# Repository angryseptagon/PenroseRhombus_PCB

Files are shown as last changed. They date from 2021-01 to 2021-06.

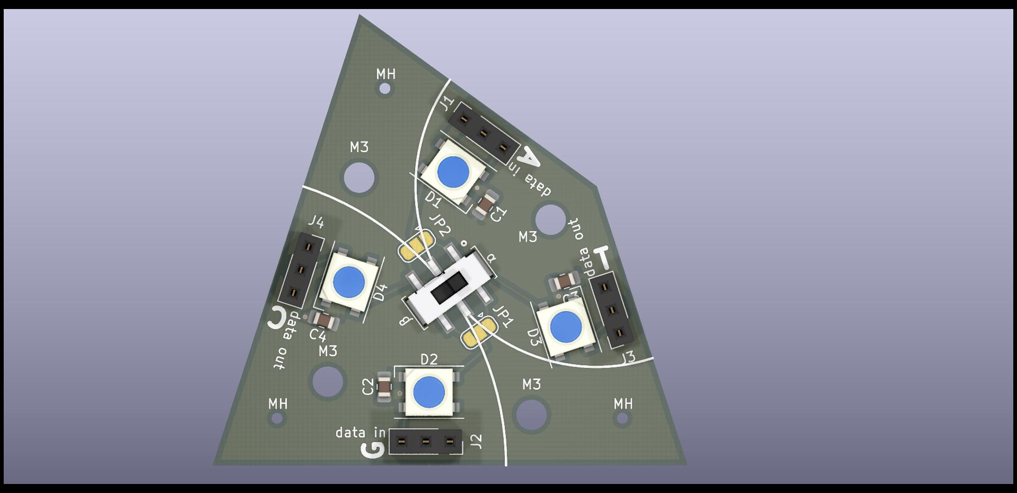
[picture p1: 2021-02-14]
Images/penrosekite_3drender.jpg

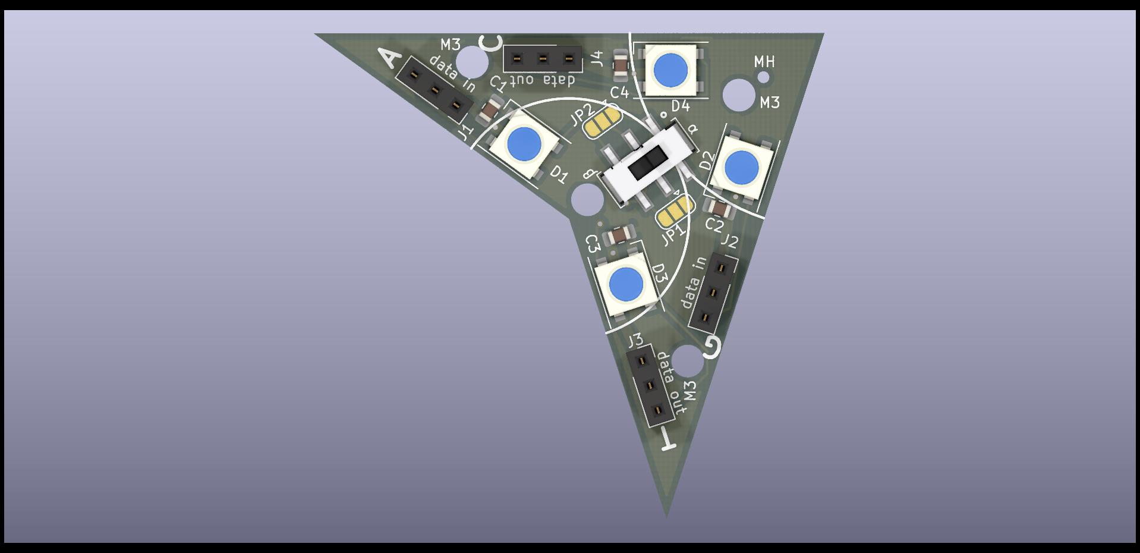
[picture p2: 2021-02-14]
Images/penrosedart_3drender.jpg

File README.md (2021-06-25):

# penroserombus_PCB
PCBs to make penrose tilings with addressable LEDs. in order to make a continous data signal, the data follows marking shown on PCB. these markings form closed loops, however loops can be merged using the switch onboard. They link together using 5mm U shaped single row connectors.
|P3 tiling|P2 tiling|
|---|---|
| thin Rhombus | Kite |
|thick Rhombus|Dart|

how switch position routes data:

Diagram

Materials per board:

4x SK6812 (or compatable ws2812b) 5050 leds - https://www.aliexpress.com/item/32814778563.html?spm=a2g0o.cart.0.0.119f3c00zzKG71&mp=1

4x 1x3 female 2.54 mm spaced headers - https://a.aliexpress.com/_mLI1pO5

4x 100 nf decoupling capacitors in 0805 size - 

?x 5mm U shaped connectors 2.54mm spacing. - https://www.aliexpress.com/item/4001034220522.html?spm=a2g0o.cart.0.0.74ea3c00vI7Rsv&mp=1

1x dpdt MSS22D18 switch - https://www.aliexpress.com/item/4000684780091.html?spm=a2g0o.cart.0.0.4ff63c00xiN8D5&mp=1

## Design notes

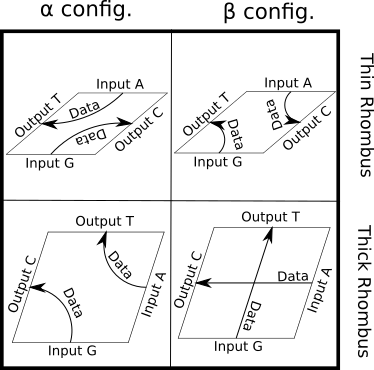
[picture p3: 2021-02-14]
Images/dataDiagram.png

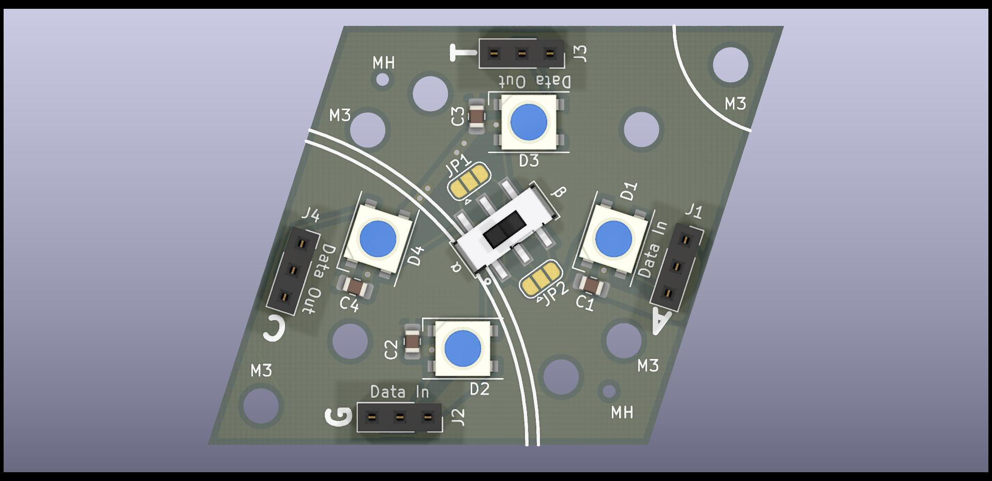
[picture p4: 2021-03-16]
Images/thick_rombus_3drender.jpg

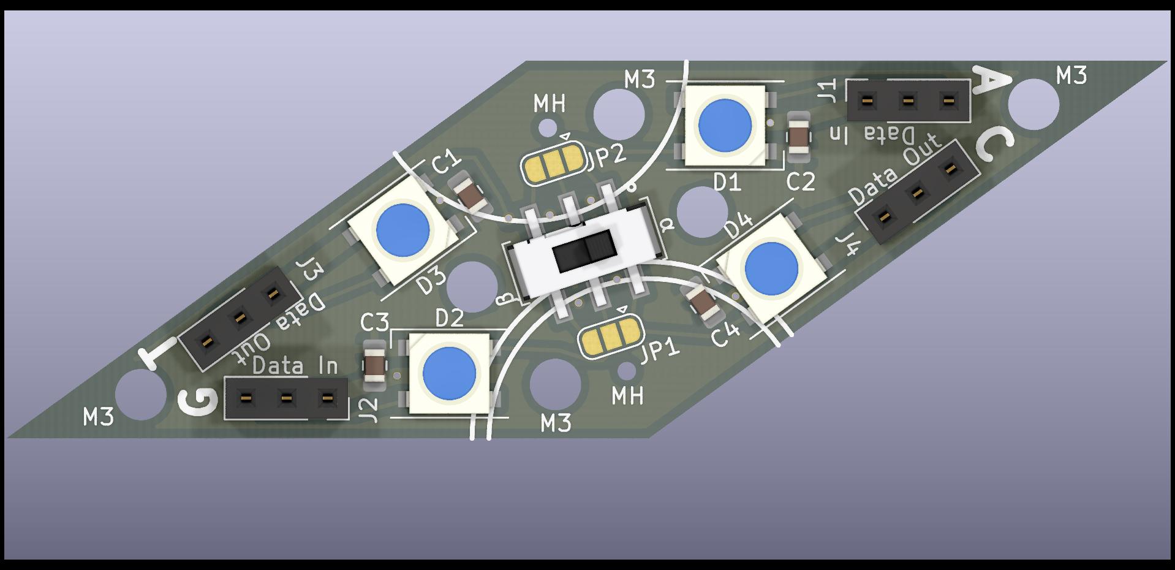
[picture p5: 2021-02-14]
Images/thin_rombus_3drender.jpg

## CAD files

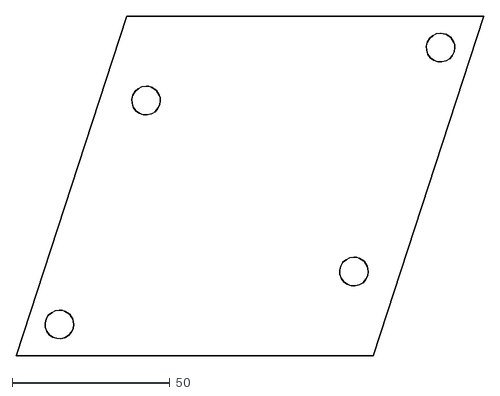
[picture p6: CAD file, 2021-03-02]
Images/penroserombus_thick_diffusercut.dxf
148.4 x 107.8

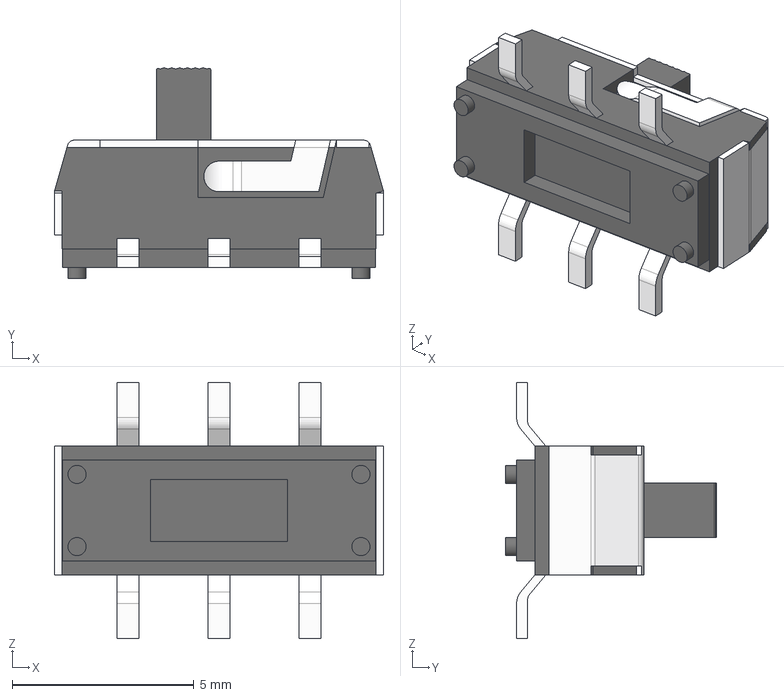
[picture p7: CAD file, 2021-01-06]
MSS22D18 Switch v3.step
9.05 x 5.79 x 7.05 mm

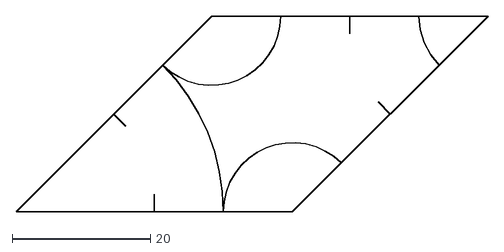
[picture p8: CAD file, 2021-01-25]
planning sketches/amann45.dxf
68.3 x 28.3

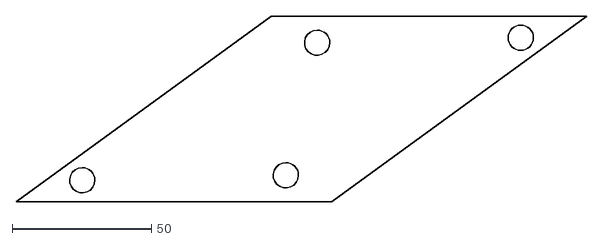
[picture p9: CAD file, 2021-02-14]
Images/penroserombus_thin_Diffusercut.dxf
205.1 x 66.6

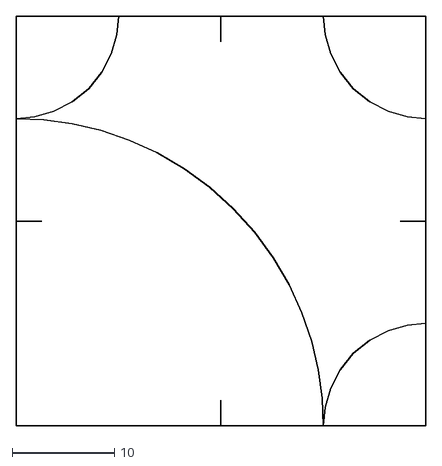
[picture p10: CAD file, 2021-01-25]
planning sketches/amannsquare.dxf
40.0 x 40.0

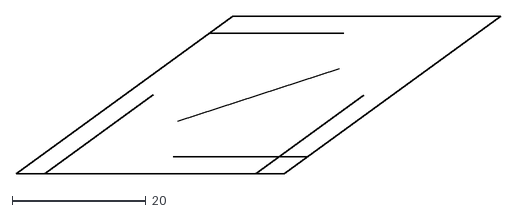
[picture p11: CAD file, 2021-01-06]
test5.dxf
72.4 x 23.5

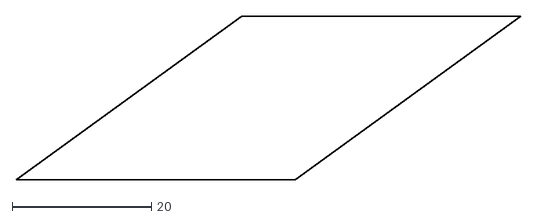
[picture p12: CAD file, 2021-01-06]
test3.dxf
72.4 x 23.5

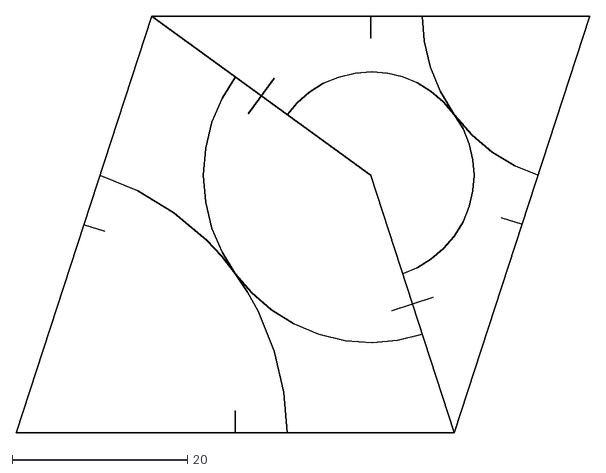
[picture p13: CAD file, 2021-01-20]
planning sketches/kiteanddarttest.dxf
65.4 x 47.6

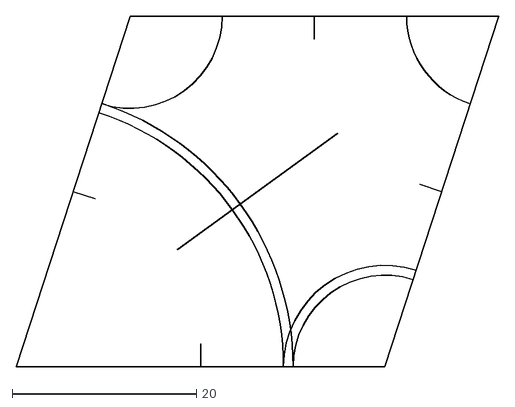
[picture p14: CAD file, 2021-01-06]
planning sketches/fixed72v2.dxf
52.4 x 38.0

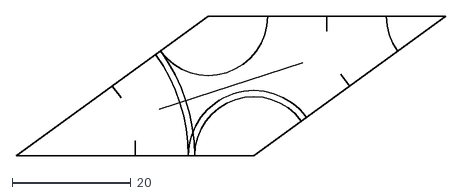
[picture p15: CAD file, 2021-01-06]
planning sketches/fixed36v2.dxf
72.4 x 23.5

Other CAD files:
planning sketches/untitled.dxf

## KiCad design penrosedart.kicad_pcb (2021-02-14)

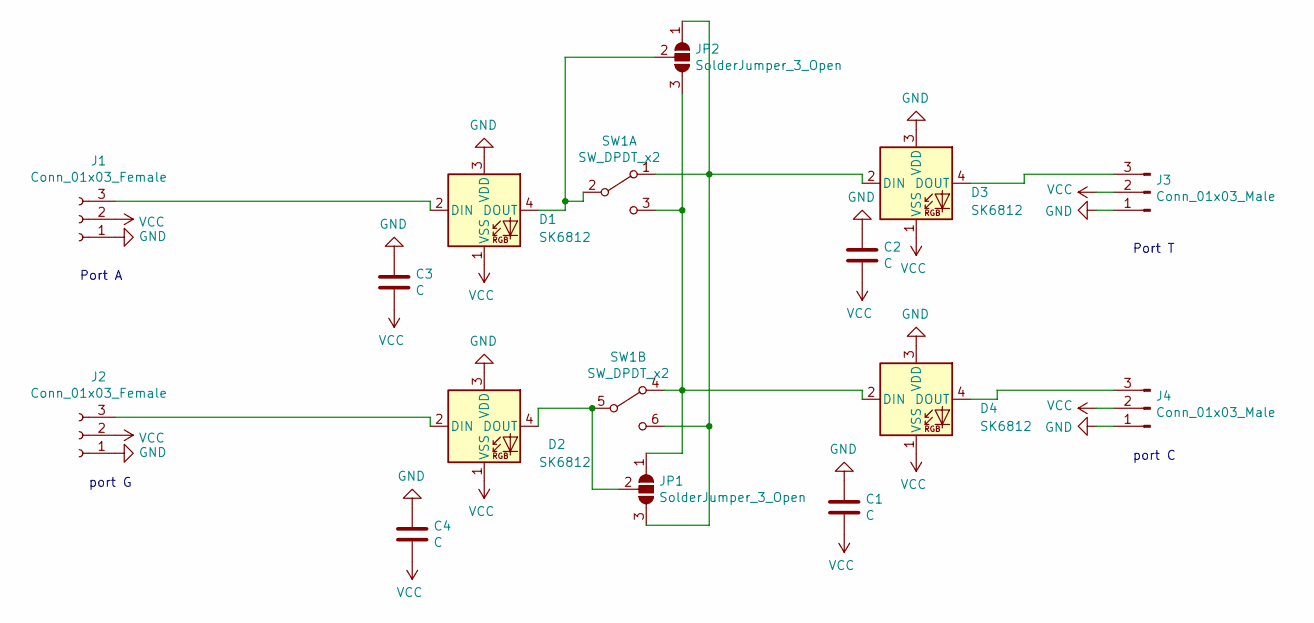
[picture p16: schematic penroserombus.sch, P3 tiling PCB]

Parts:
C1, C2, C3, C4: C; C_0805_2012Metric_Pad1.18x1.45mm_HandSolder
D1, D2, D3, D4: SK6812; LED_SK6812_PLCC4_5.0x5.0mm_P3.2mm
J1, J2: Conn_01x03_Female; PinSocket_1x03_P2.54mm_Vertical
J3, J4: Conn_01x03_Male; PinSocket_1x03_P2.54mm_Vertical
JP1, JP2: SolderJumper_3_Open; SolderJumper-3_P1.3mm_Open_RoundedPad1.0x1.5mm
SW1: SW_DPDT_x2; Aliexpress_slideswitch_2P2T

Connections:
GND: C1.1, C2.1, C3.1, C4.1, D1.3 (VDD), D2.3 (VDD), D3.3 (VDD), D4.3 (VDD), J1.1, J2.1, J3.1, J4.1
unnamed: D1.2 (DIN), J1.3
unnamed: D1.4 (DOUT), JP2.2 (C), SW1.2 (B)
unnamed: D2.2 (DIN), J2.3
unnamed: D2.4 (DOUT), JP1.2 (C), SW1.5 (B)
unnamed: D3.2 (DIN), JP1.3 (B), JP2.1 (A), SW1.1 (A), SW1.6 (C)
unnamed: D3.4 (DOUT), J3.3
unnamed: D4.2 (DIN), JP1.1 (A), JP2.3 (B), SW1.3 (C), SW1.4 (A)
unnamed: D4.4 (DOUT), J4.3
VCC: C1.2, C2.2, C3.2, C4.2, D1.1 (VSS), D2.1 (VSS), D3.1 (VSS), D4.1 (VSS), J1.2, J2.2, J3.2, J4.2

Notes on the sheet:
port G
port C
Port A
Port T

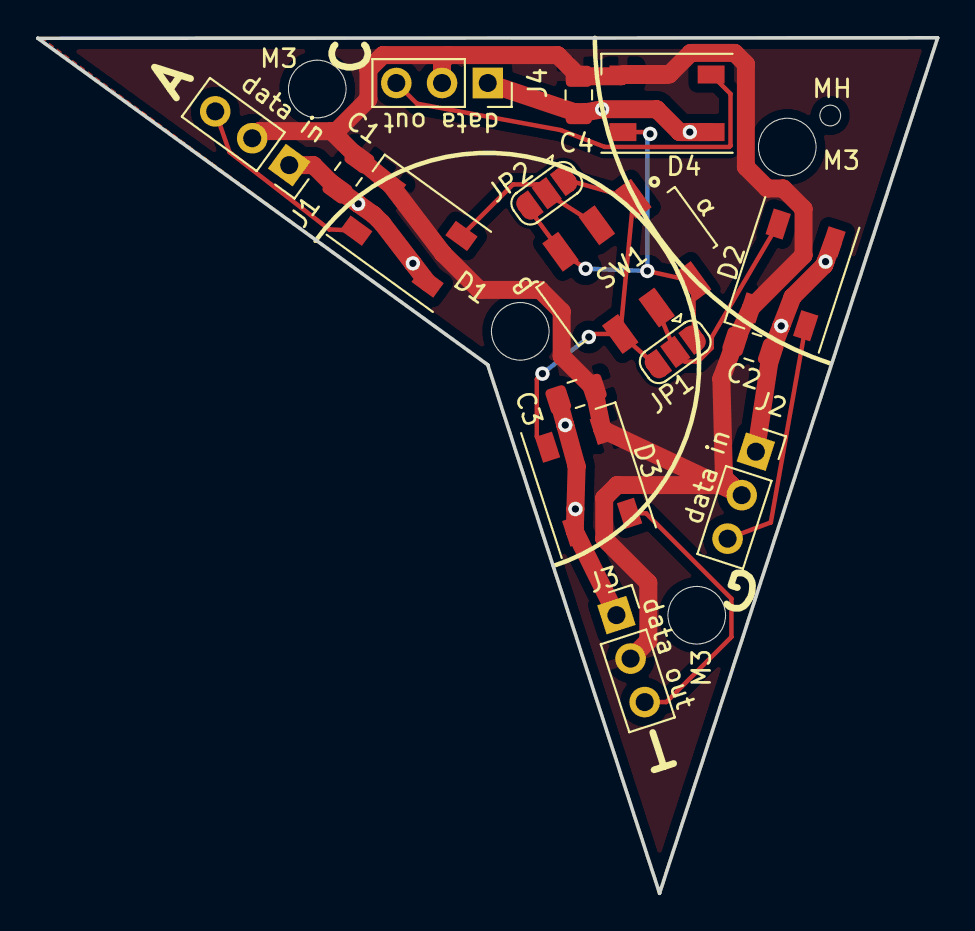
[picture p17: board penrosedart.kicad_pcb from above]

Board: 2 copper layers, 50.0 x 47.5 mm, 20 parts (0 on the bottom side), 10 nets.

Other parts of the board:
M3, M3#2, M3#3, M3#4: MountingHole_3.2mm_M3_ISO7380
MH: Pushpin_mountinghole

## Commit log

2021-01-06 initial upload
    learning how to use github, might goof it up
    [coordinate.ods, penroserombus.sch, penroserombus_thick_40mm.kicad_pcb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]
2021-01-06 initial upload
    idk whats going on anymore
    [penroserombus_thin_40mm-B_Cu.gbr, penroserombus_thin_40mm-B_Mask.gbr, penroserombus_thin_40mm-B_Paste.gbr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]
2021-01-06 deleting some trash
    [penroserombus_thin_40mm-B_Cu.gbr, penroserombus_thin_40mm-B_Mask.gbr, penroserombus_thin_40mm-B_Paste.gbr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]
2021-01-06 ok third time is a charm
    [fixed36v2.dxf, fixed72v2.dxf, penroserombus.sch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]
2021-01-06 added 3d model of switch from softegg's project
    [MSS22D18 Switch v3.step, penroserombus_thick_40mm.kicad_pcb, penroserombus_thin_40mm.kicad_pcb]
2021-01-06 updated gerbers
    [penroserombus_thick_40mm-B_Cu.gbr, penroserombus_thick_40mm-B_Mask.gbr, penroserombus_thick_40mm-B_Paste.gbr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]
2021-01-07 added more mounting holes and generated gerbers
    [penroserombus_thick_40mm-B_Cu.gbr, penroserombus_thick_40mm-B_Mask.gbr, penroserombus_thick_40mm-B_Paste.gbr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]
2021-01-13 board has 4 leds instead of 2.
    [penroserombus.sch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]
2021-01-13 fixed led 4 orientation
    [penroserombus_thick_40mm.kicad_pcb]
2021-01-13 updated thick rombus gerbers.
    [penroserombus_thick_40mm-B_Cu.gbr, penroserombus_thick_40mm-B_Mask.gbr, penroserombus_thick_40mm-B_Paste.gbr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]
2021-01-14 rearranged leds a bit.
    [penroserombus_thick_40mm.kicad_pcb]
2021-01-14 made gerbers
    [penroserombus.sch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]
2021-01-17 small tweaks to traces
    [penroserombus_thick_40mm-B_Cu.gbr, penroserombus_thick_40mm-B_Mask.gbr, penroserombus_thick_40mm-B_Paste.gbr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]
2021-01-17 updated gerber zip files
2021-01-20 added kite and dart tiling
    idk why im doing this
    [amann45.dxf, amannsquare.dxf, kiteanddarttest.dxf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]
2021-01-21 shifted ports on penrose rhombi to enforce all matching rules. fixed flipped ports on penrose dart.
    going to make new gerbers later.
    [penrosedart.kicad_pcb, penrosekite.kicad_pcb, penroserombus_thick_40mm.kicad_pcb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]
2021-01-22 updated gerbers and images. new gerbers of rombi now enforce the tiling rules by making ports misalign when.
    [penrosedart-B_Cu.gbr, penrosedart-B_Mask.gbr, penrosedart-B_Paste.gbr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]
2021-01-22 small tweaks to thick rhombus.
    shifted letters and moved jumpers closer to switch
    [penroserombus_thick_40mm-B_Cu.gbr, penroserombus_thick_40mm-B_Mask.gbr, penroserombus_thick_40mm-B_Paste.gbr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]
2021-01-25 increased mounting hole size to M3
    increased mounting hole size to M3 to accomidate plastic adhesive mounting hole standoffs. makes the silkscreen a bit cramped and the VCC route a bit long, but maybe I will make the top pour VCC inst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
    [amann45.dxf, amannsquare.dxf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]
2021-01-26 updated penrose dart with powerplane
    [penrosedart-B_Cu.gbr, penrosedart-B_Mask.gbr, penrosedart-B_Paste.gbr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]
2021-01-29 board wiring changes and mounting hole additions for adhesive standoffs
    changed top copper fill to VCC and added mounting holes with new footprint to check if the mounts collided.
    [penrosedart.kicad_pcb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]
2021-02-14 minor tweaks and diagrams
    Tweaks to silkscreen and stuff also added a diagram to explain switch on board. Also made top layer VCC on penrose kite.
    [penrosedart.kicad_pcb, penrosekite.kicad_pcb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]
2021-02-19 added even more mounting holes
    honestly these boards are starting to look like swiss cheese but seeing how prototyping is expensive, I want to have my bases covered.
    [penroserombus_thick_40mm-B_Cu.gbr, penroserombus_thick_40mm-B_Mask.gbr, penroserombus_thick_40mm-B_Paste.gbr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]
2021-03-02 leftover miscellaneous updates.
    [penroserombus_thick_40mm-B_Cu.gbr, penroserombus_thick_40mm-B_Mask.gbr, penroserombus_thick_40mm-B_Paste.gbr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]
